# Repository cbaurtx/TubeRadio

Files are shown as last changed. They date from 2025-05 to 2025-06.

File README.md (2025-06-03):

# TubeRadio
## Disclaimer
It is entirely your responsibility to comply with all 
applicable laws when possesing or operating this radio.
It is entirely your responsibility to make sure the all circuits, including the powersupply are operated safely.
## License
TubeRadio is covered by CERN-OHL-W (Weakly reciprocal) 
Refer to doc/LICENSE.md for the license text
## Notes
### Output Transformer
There is a DC bias flowing through the output transformer. To avoid magnetic saturation of the iron core the core needs a small paper/plastic gap (~0.1–0.3 mm) between E and I laminations of the E I core. Do not use a power
transformer or an audio transformer or a push pull amplifier.
### Anode Choke
Similar to the output transformer the anode choke L4 has a DC bias current. So this choke needs
a similar air gap as the output transformer to avoid magnetic saturation of the iron core.

### Input Tank and Tickler Coil
The target frequency range of this radio is from 1.50MHz to 4.25MHz. With a capacity of 70pF to 570pF we can calculate the inductance of the coil of the input tank.

**f₀ = 1 / (2π × √(L × C))**

**f₀** is the resonance frequency in hertz (Hz)

**L** is the inductance in henrys (H)

**C** is the capacitance in farads (F)

To get the calculted inductance of 20µH the input tank 
coil we need this air coil:

|Entity |Value|Unit|
|---|-----|----|
|Turns  |25 |# |
|Layers |2 |# |
|Inner ø|13 |mm  |
|Wire ø |0.9  |mm  |

The antenna and the tickler coil both have 8 turns.
The antenna coil is wound on top of the input tank coil and the tickler coil is side by side of the other coils at a distance of 10mm.

The design files are for KiCad version 9.

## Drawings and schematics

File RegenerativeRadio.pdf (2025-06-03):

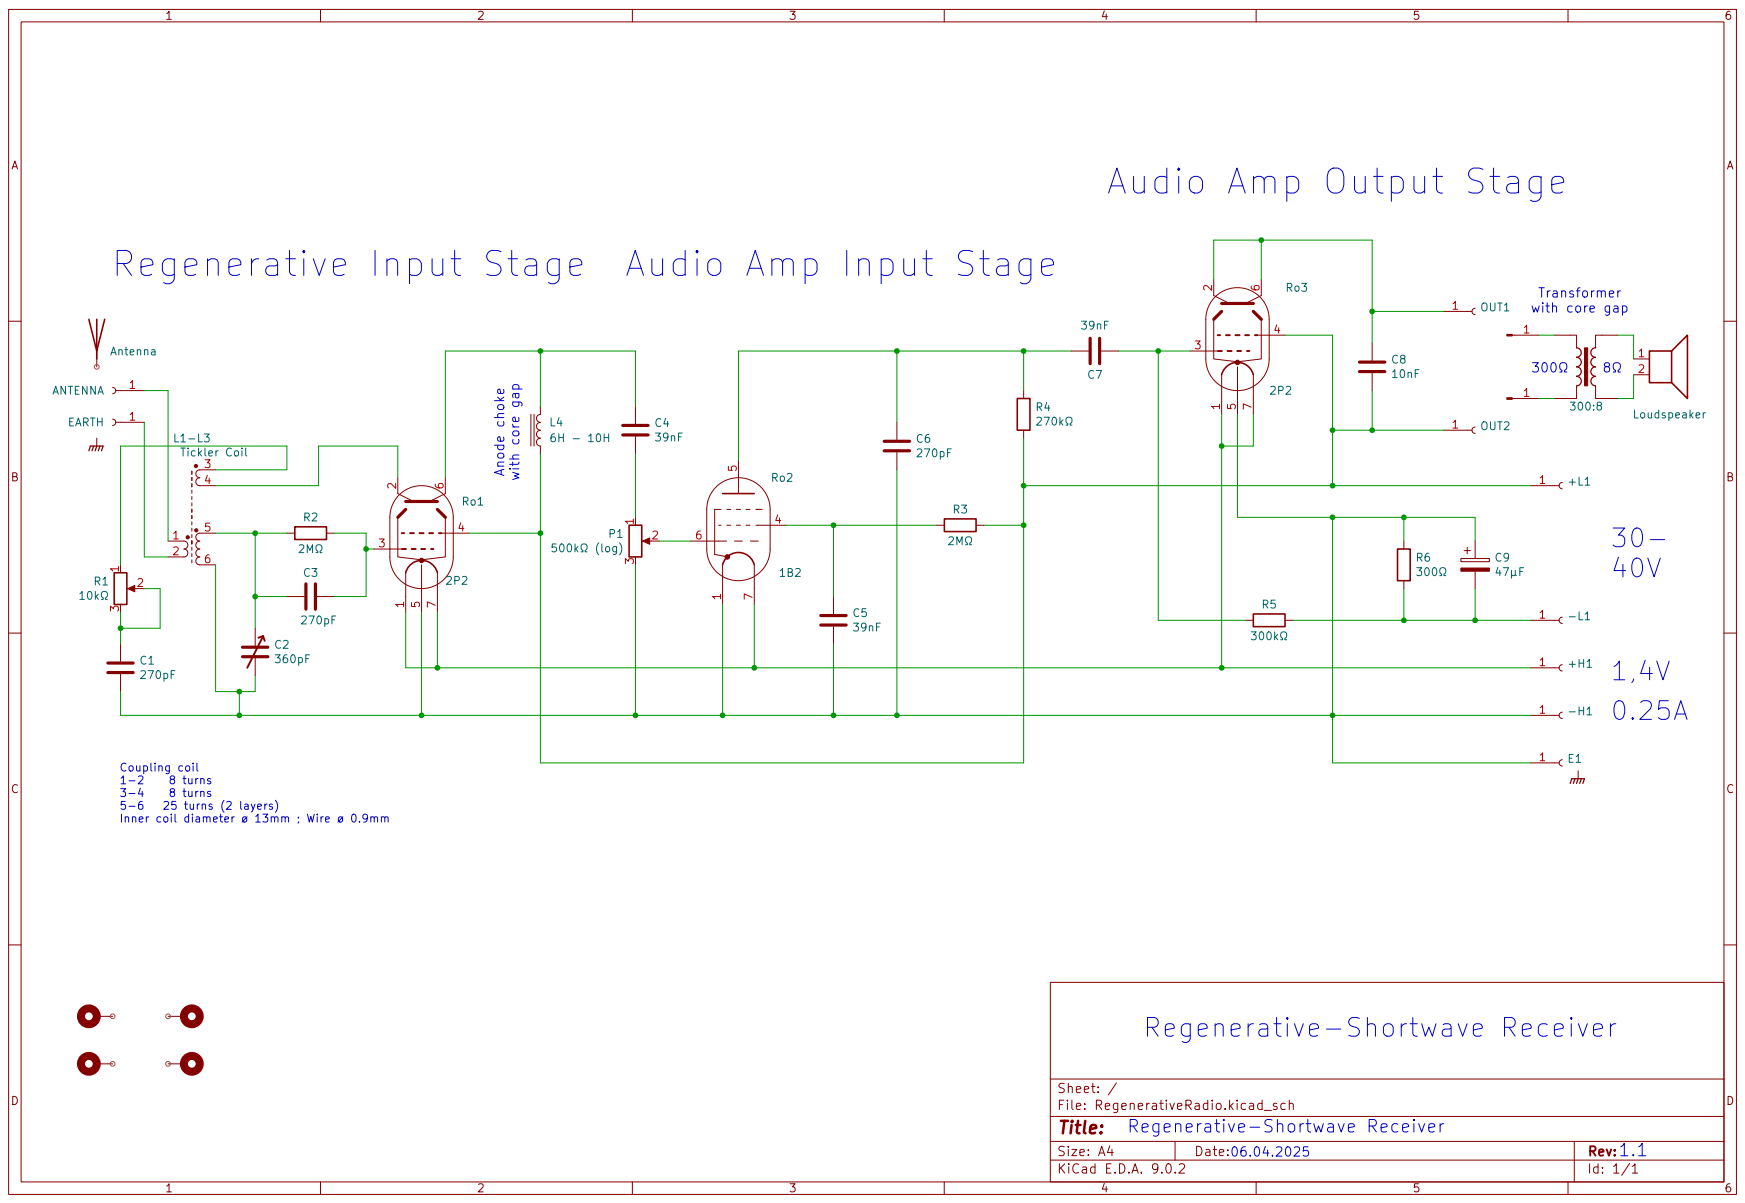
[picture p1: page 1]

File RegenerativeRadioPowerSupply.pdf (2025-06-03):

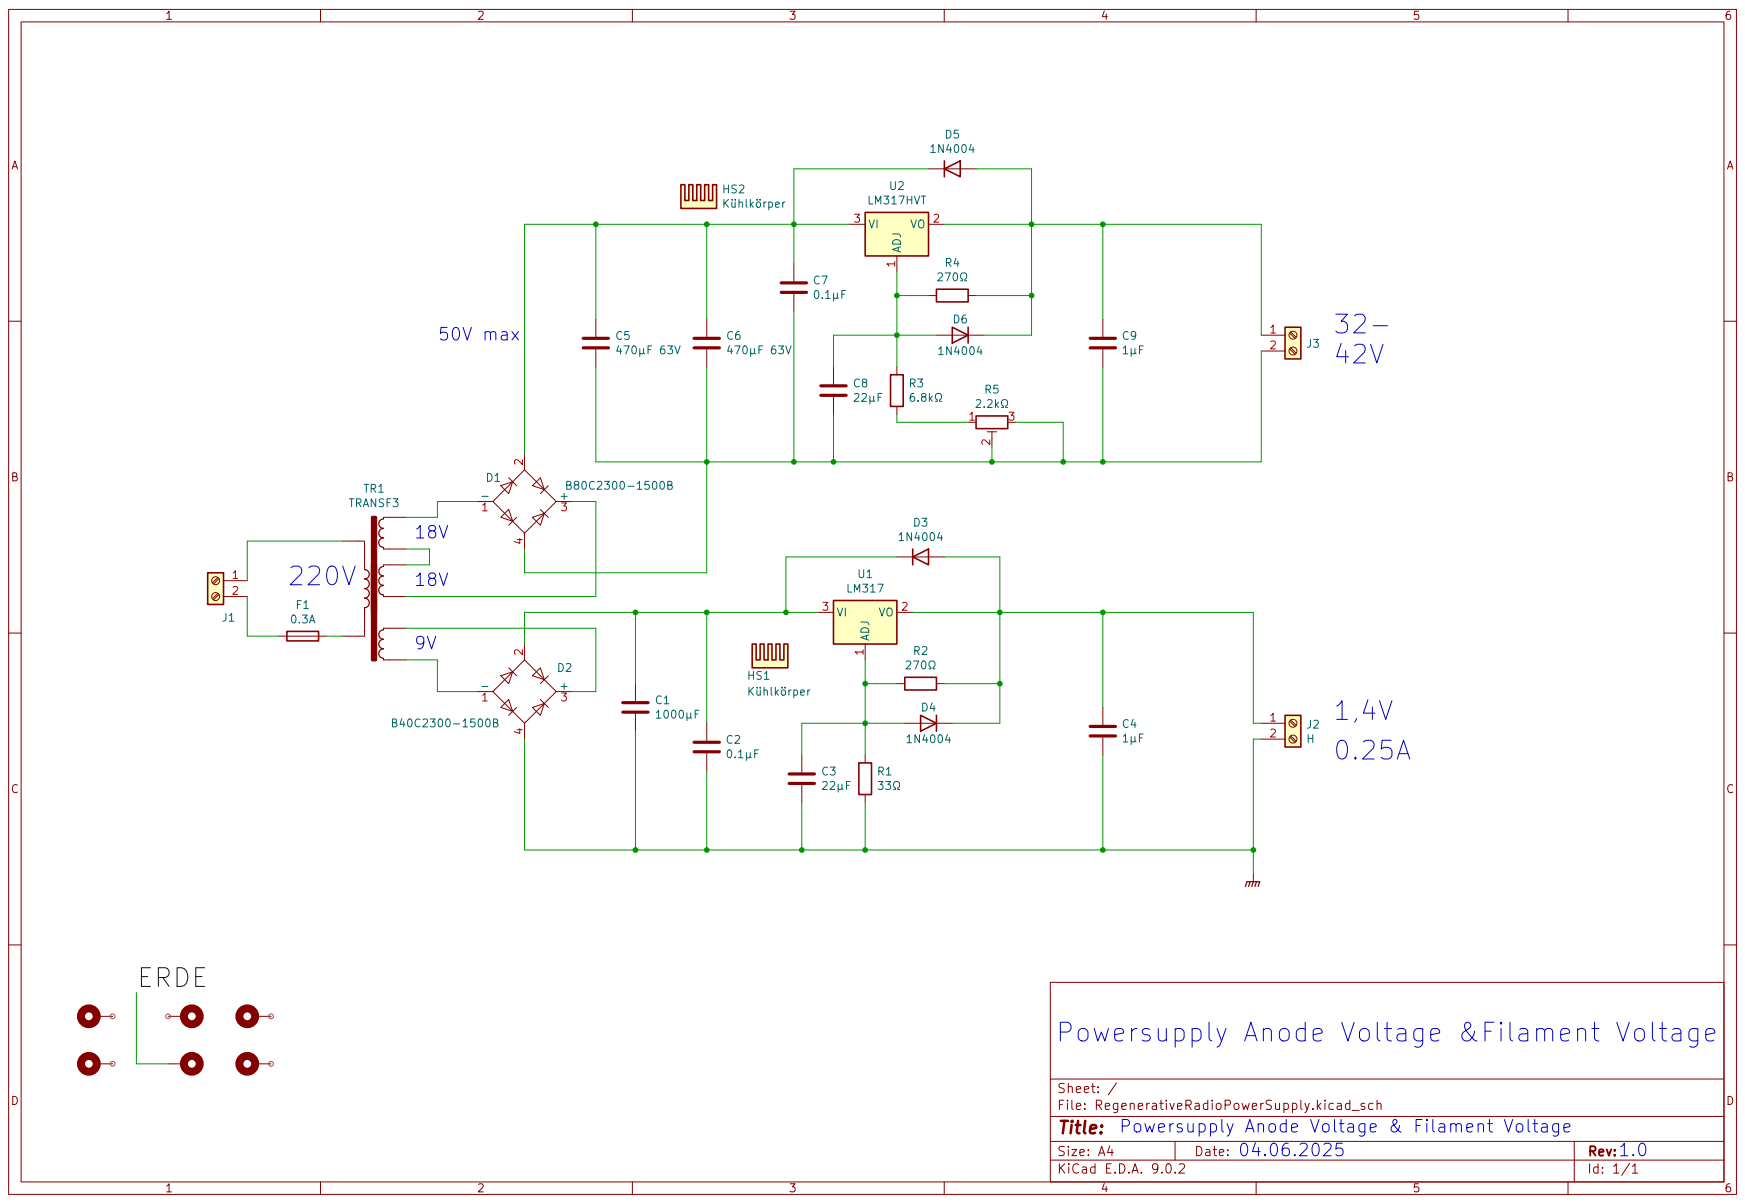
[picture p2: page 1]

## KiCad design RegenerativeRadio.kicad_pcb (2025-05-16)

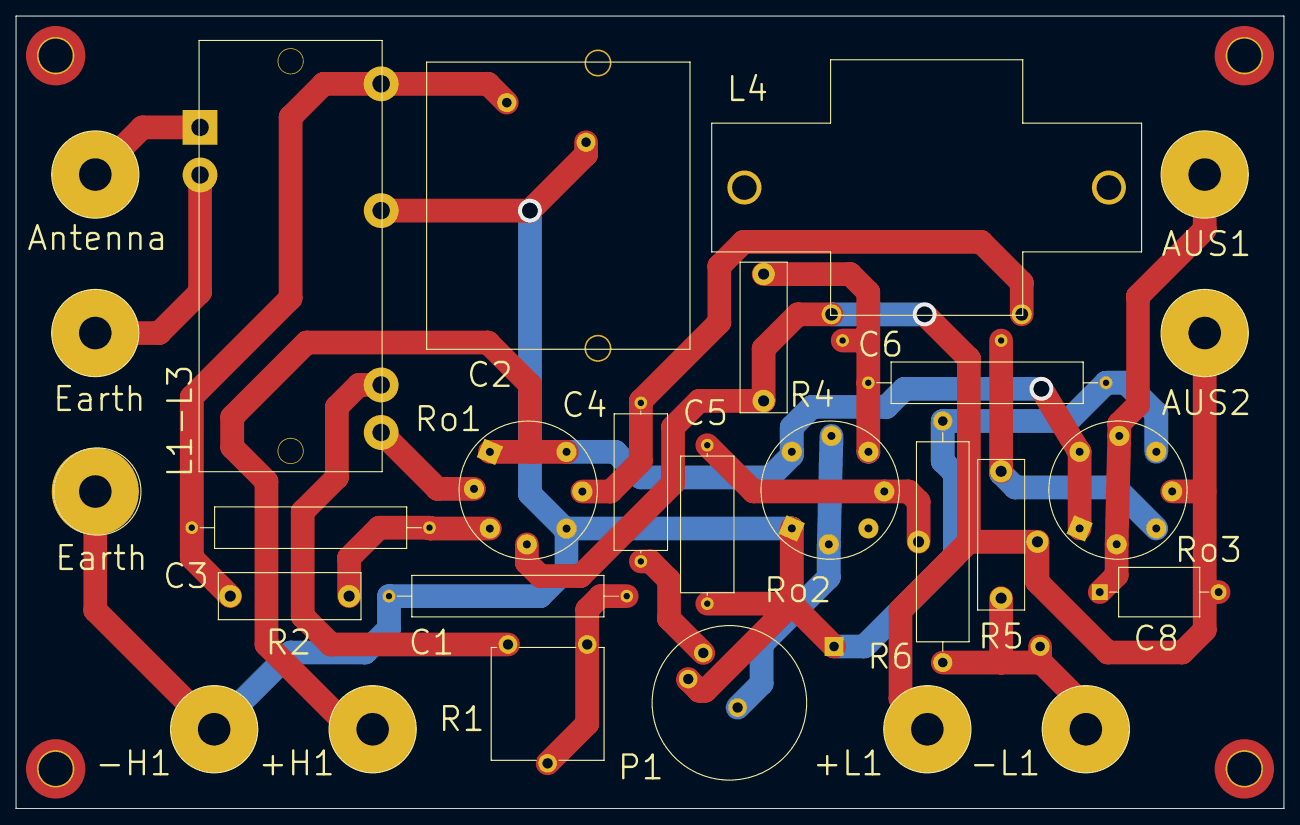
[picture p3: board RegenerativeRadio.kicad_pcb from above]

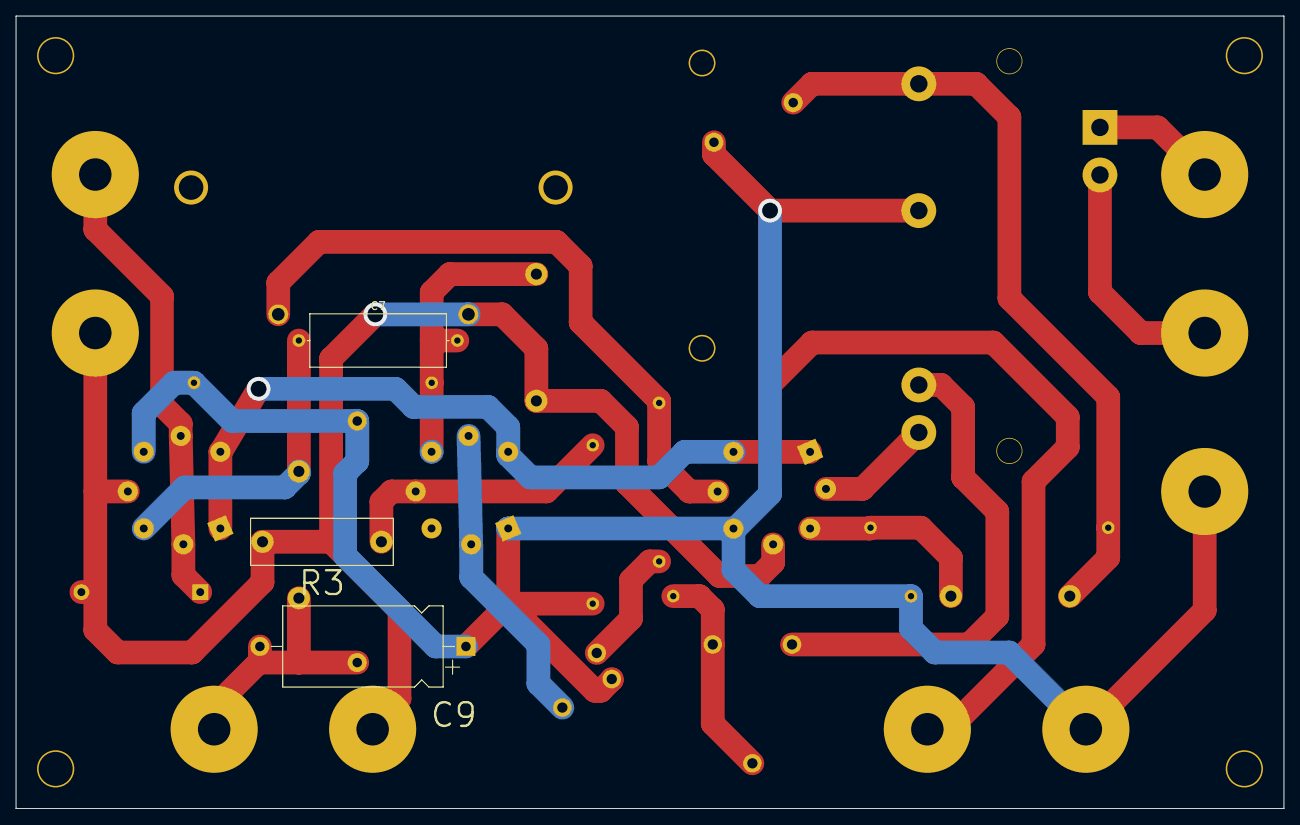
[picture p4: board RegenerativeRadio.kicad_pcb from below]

Board: 2 copper layers, 160.0 x 100.0 mm, 34 parts (3 on the bottom side), 18 nets.

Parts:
+H1: Conn_01x01_Female; Banana_Jack_Terminal_1Pin
+L1: Conn_01x01_Female; Banana_Jack_Terminal_1Pin
-H1: Conn_01x01_Female; Banana_Jack_Terminal_1Pin
-L1: Conn_01x01_Female; Banana_Jack_Terminal_1Pin
ANTENNE1: Conn_01x01_Female; Banana_Jack_Terminal_1Pin
AUS1, AUS2: Conn_01x01_Female; Banana_Jack_Terminal_1Pin
C1, C3, C6: 270pF; C_Axial_L25.0mm_D5.0mm_P30.00mm_Horizontal
C2: 360pF; C_Var_L36mm_W33mm
C4, C5, C7: 39nF; C_Axial_L17.0mm_D6.5mm_P20.00mm_Horizontal
C8: 10nF; C_Axial_L10.0mm_D6.0mm_P15.00mm_Horizontal
C9: 47µF; CP_Axial_L20.0mm_D10.0mm_P26.00mm_Horizontal
E1: Erde; Banana_Jack_Terminal_1Pin
ERDE1: Conn_01x01_Female; Banana_Jack_Terminal_1Pin
H1, H2, H3, H4: MountingHole_Pad; MountingHole_4.3mm_M4_DIN965_Pad_TopOnly
L1-L3: Koppelspule; L_Antennal_L72mm_D23mm
L4: 10H; L_37mmx15mm
P1: 500kΩ; Potentiometer_Round_D19_Vertical
R1: 10kΩ; Potentiometer_ACP_CA14V-15_Vertical
R2, R3: 2MΩ; R_Vintage_17mm_D7mm_P15mm_Horizontal
R4: 270kΩ; R_Vintage_17mm_D7mm_P16mm_Horizontal
R5: 300kΩ; R_Vintage_17mm_D7mm_P16mm_Horizontal
R6: 300Ω; R_Axial_Power_L25.0mm_W6.4mm_P30.48mm
Ro1, Ro3: 2P2; Valve_Mini_P
Ro2: 1B2; Valve_Mini_P

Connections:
unnamed: +H1.1, Ro1.1, Ro1.7, Ro2.7, Ro3.1, Ro3.7
unnamed: +L1.1, AUS2.1, C8.2, L4.1, R3.2, R4.2, Ro1.4, Ro3.4
unnamed: -H1.1, C1.2, C2.2, C5.2, C6.2, C9.1, E1.1, L1-L3.6, P1.3, R6.1, Ro1.5, Ro2.1, Ro3.5
unnamed: -L1.1, C9.2, R5.2, R6.2
unnamed: ANTENNE1.1, L1-L3.1
unnamed: AUS1.1, C8.1, Ro3.2, Ro3.6
unnamed: C1.1, R1.2, R1.3
unnamed: C2.1, C3.2, L1-L3.5, R2.1
unnamed: C3.1, R2.2, Ro1.3
unnamed: C4.1, L4.2, Ro1.6
unnamed: C4.2, P1.1
unnamed: C5.1, R3.1, Ro2.4
unnamed: C6.1, C7.2, R4.1, Ro2.5
unnamed: C7.1, R5.1, Ro3.3
unnamed: ERDE1.1, L1-L3.2
unnamed: L1-L3.3, R1.1
unnamed: L1-L3.4, Ro1.2
unnamed: P1.2, Ro2.6

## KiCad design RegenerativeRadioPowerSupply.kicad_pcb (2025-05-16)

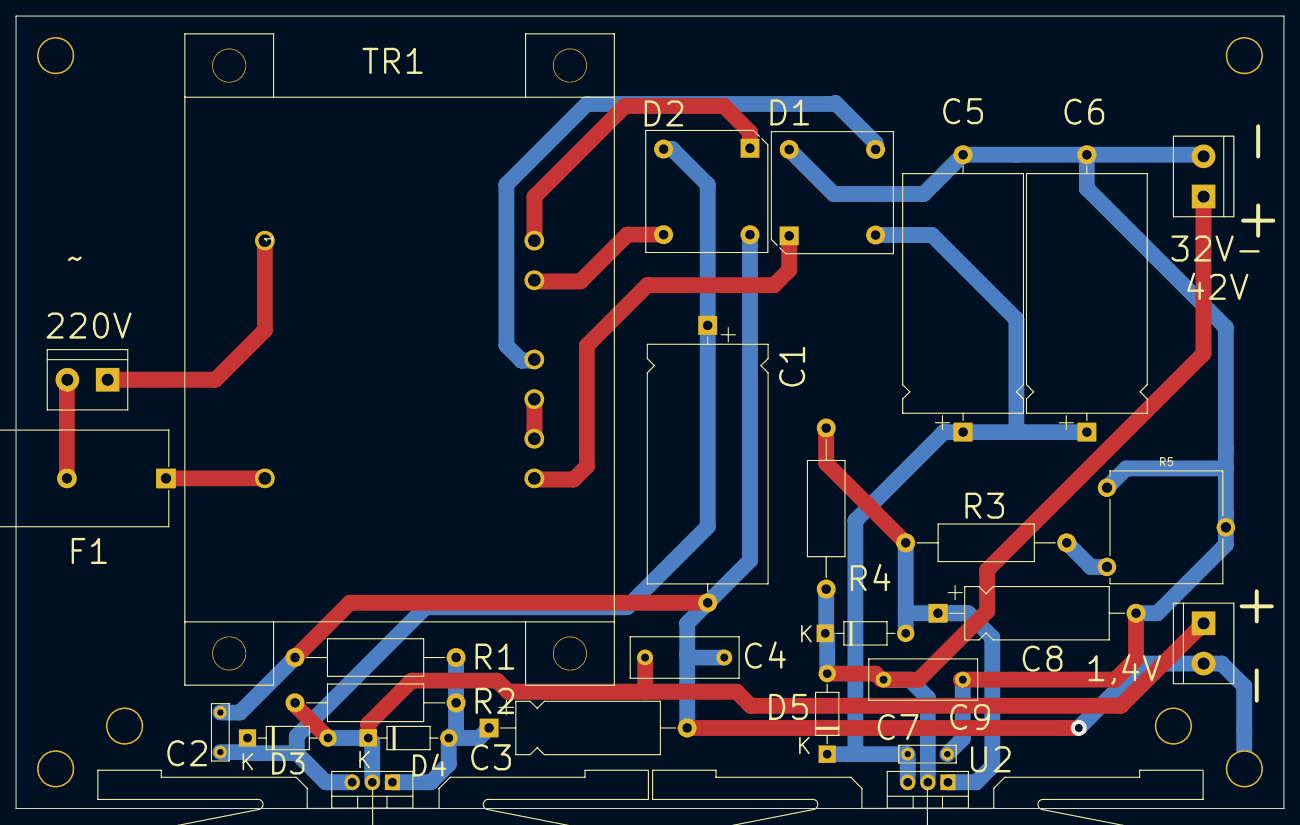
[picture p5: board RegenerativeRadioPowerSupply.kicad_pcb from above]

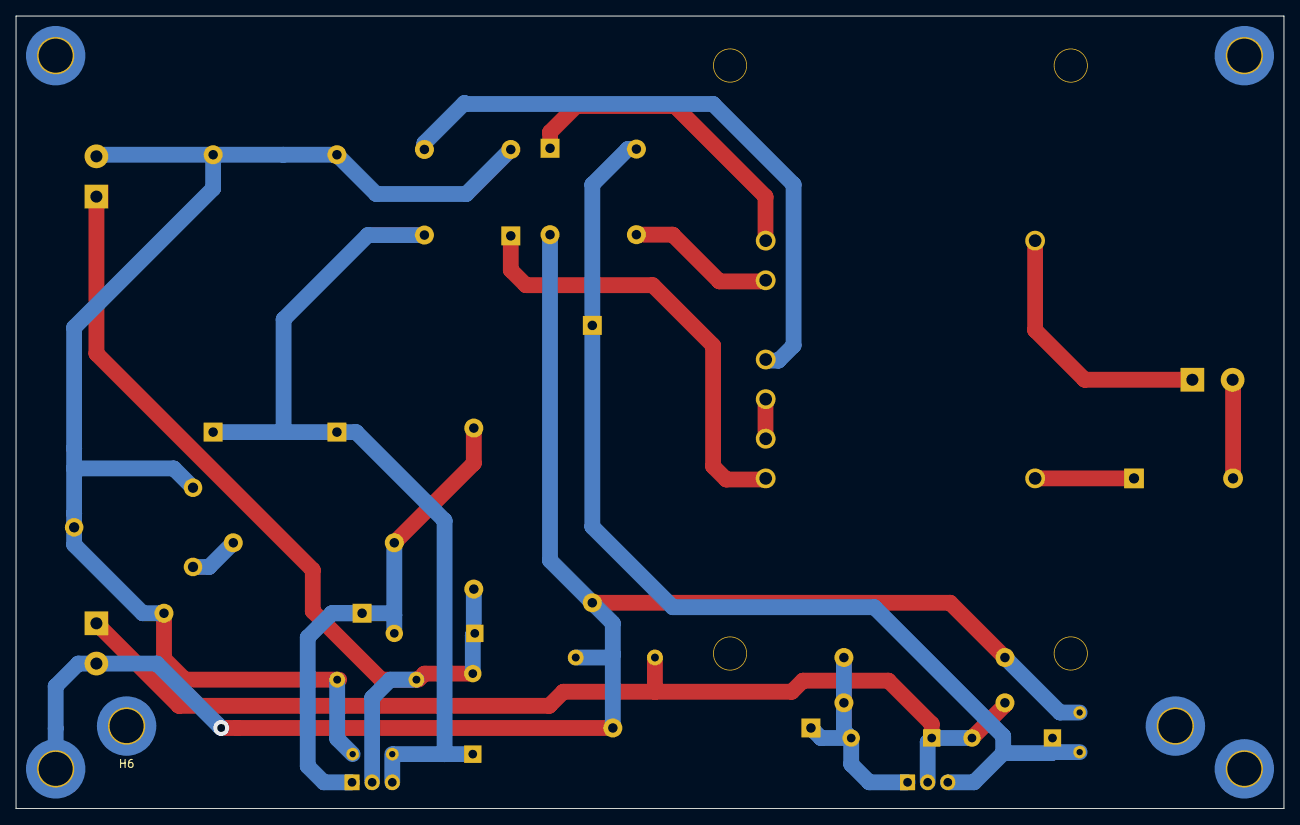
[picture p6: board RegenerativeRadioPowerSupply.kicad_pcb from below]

Board: 2 copper layers, 160.0 x 100.0 mm, 35 parts (6 on the bottom side), 17 nets.

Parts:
C1: 1000µF; CP_Axial_L30.0mm_D15.0mm_P35.00mm_Horizontal
C2, C7: 0.1µF; C_Rect_L7.0mm_W2.0mm_P5.00mm
C3, C8: 22µF; CP_Axial_L18.0mm_D6.5mm_P25.00mm_Horizontal
C4, C9: 1µF; C_Rect_L13.5mm_W5.0mm_P10.00mm_FKS3_FKP3_MKS4
C5, C6: 470µF 63V; CP_Axial_L30.0mm_D15.0mm_P35.00mm_Horizontal
D1, D2: B40C2300-1500B; Diode_Bridge_15.1x15.1x6.3mm_P10.9mm
D3, D4, D5, D6: 1N4004; D_DO-41_SOD81_P10.16mm_Horizontal
F1: 0.3A; Fuseholder_Cylinder-5x20mm
H1, H2, H3, H4, H5, H6: MountingHole_Pad; MountingHole_4.3mm_M4_DIN965_Pad_TopOnly
HS1, HS2: Heatsink; Heartsink_TO220_ver
J1: Screw_Terminal_01x02; TerminalBlock_bornier-2_P5.08mm
J2: H; TerminalBlock_bornier-2_P5.08mm
J3: L; TerminalBlock_bornier-2_P5.08mm
R1: 33Ω; R_Axial_DIN0414_L11.9mm_D4.5mm_P20.32mm_Horizontal
R2, R4: 270Ω; R_Axial_DIN0414_L11.9mm_D4.5mm_P20.32mm_Horizontal
R3: 6.8kΩ; R_Axial_DIN0414_L11.9mm_D4.5mm_P20.32mm_Horizontal
R5: 2.2kΩ; Potentiometer_ACP_CA14V-15_Vertical
TR1: TRANSF3; Transmformer_220V-18V_18V_9V
U1: LM317; TO-220-3_Vertical
U2: LM317HVT; TO-220-3_Vertical

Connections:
/ERDE: C1.2, C2.2, C3.2, C4.2, D2.4, H4.1, J2.2, R1.2
unnamed: C1.1, C2.1, D2.2, D3.1, U1.3
unnamed: C3.1, D4.2, R1.1, R2.1, U1.1
unnamed: C4.1, D3.2, D4.1, J2.1, R2.2, U1.2
unnamed: C5.1, C6.1, C7.1, D1.2, D5.1, U2.3
unnamed: C5.2, C6.2, C7.2, C8.2, C9.2, D1.4, J3.2, R5.2, R5.3
unnamed: C8.1, D6.2, R3.1, R4.1, U2.1
unnamed: C9.1, D5.2, D6.1, J3.1, R4.2, U2.2
unnamed: D1.1, TR1.3
unnamed: D1.3, TR1.6
unnamed: D2.1, TR1.8
unnamed: D2.3, TR1.7
unnamed: F1.1, TR1.2
unnamed: F1.2, J1.2
unnamed: J1.1, TR1.1
unnamed: R3.2, R5.1
unnamed: TR1.4, TR1.5

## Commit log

2025-06-01 Update documentation, add LM317 simultion
    [LM317_OutputVoltage.ods, RegenerativeRadio.kicad_sch, Vreg.kicad_sch]
2025-06-01 Update RegenerativeRadio.kicad_sch
    Change value of anode choke L4. Inductance range is 6H to 10H.
    [RegenerativeRadio.kicad_sch]
2025-06-03 Added load to voltage regulator simulation
    [Vreg.kicad_sch]
2025-06-03 Added PDF pf schematics
